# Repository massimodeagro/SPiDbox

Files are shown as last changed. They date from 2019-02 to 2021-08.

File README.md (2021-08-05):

# SPiDbox: a Skinnerbox system to train jumping SPiDers based on the Raspberry Pi

## Before we start
A full description of the SPiDbox, as well as the experimental validation, is available in the Journal of Neuroscience Methods (https://doi.org/10.1016/j.jneumeth.2020.108925). if you use the system, please cite the paper.

## This GitHub page contains:
* In the "3D_models" folder, the .scad files of all the components to 3d print
* In the "OS" folder, the full python script, that will have to be copied in the home folder of the Raspberry Pi (see the installation guide)
* In the "Electronics" folder, a pdf depicting how the circuit needs to be built
* The "screenImages" folder is part of a work in progress. For now, it only needs to be copied inside the home folder of the Raspberry Pi

**Inside each folder you will find a guide for printing, installation and building, respectively.**

For any request or comment, please contact me at *massimo.de-agro@ur.de*. I would like to make the guides as user-friendly as possible, so every suggestion is highly appreciated.

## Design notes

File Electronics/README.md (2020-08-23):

# Preparing the circuit

In this folder, you will find a PDF with the schematic of the circuit. If you wish to make your own circuit board, just follow the schematic. If you instead prefer, you can download the zip containing the Gerber file (this have been generated with easyEDA https://easyeda.com/

## Things you will need

Before starting, you will need to acquire some components. The following are all trough hole components (THC):
* 49 male pin 2.54mm-pitch connectors, like [this](https://www.pololu.com/product/965). Specifically, you will need a 2x20 long strip, a 5 long strip and a 4 long strip.
* 26 female pin 2.54mm-pitch connectors, like [this](https://www.pololu.com/product/1030). Specifically, you will need two 8-long strips and one 10-long strip. If you buy a single long female pin connector strip, be aware that by cutting it you will lose the connector on the cut position, so buy a slightly longer strip.
* A two pin 2.54mm-pitch jst-xh connector, like [this](https://www.pololu.com/product/2717)
* A four-pin 2.54mm-pitch jst-xh connector, of the same type of the one above
* A stepper motor driver. In the schematic, an A4988 is reported, but many drivers have the same pinout structure. Just be sure that the pins positions are the same as in the A4988
* A rotary encoder with its breakout board.
* An SSD1306 OLED screen with its breakout board.
* An ADS1115 analog to digital converted with its breakout board.
* 5 1kohm resistor.
* 1 1N4448 diode.
* 1 BD139 transistor.
* 1 100uf electrolytic capacitor.
* 5 female 3.5mm jack connectors (to solder onto the board, so it needs to be a THC component).
* 5 male 3.5mm jack connectors (to solder to a cable).
* 1 female power jack connector (to solder onto the board, so THC).
* 1 lm2596 buck converter.
* 1 12V, at least 5A power supply.
* 1 female to female 2x20 jumper wire. this is to connect the raspberry to the circuit board.
* 9 female to female jumper wire.
* A 12V led strip.
* A soldering iron and solder.

## Things to do to successfully solder your board

The process of building the board is straight forward, just solder the right components on their places. But you will need to take some care.

* Note that the board has a front and a back side. The front side presents the name of the SPiDbox on the bottom right.
* Solder two 20 long male strips on the raspberry pi slot on the board. The strips need to end up having the long pin sticking out from the back side of the board. So while looking at the board back side, fit in the holes the short end of the pin, then solder the protruding end from the front.
* All other components will stick out from the front face.
* The connectors for the OLED screen and the rotary encoder will be done with the remaining male strip pins, as these two components will not sit on the board, but will be attached to the front of the SPiDbox. 
* For the stepper motor driver and the ADS, use female connectors.
* Next, solder the two jst-xh in their respective places
* Solder in the resistors, the diode and the capacitor (be aware of capacitor polarity)
* Solder in the 3.5mm jacks and the power jack
* Lastly, solder the buck converter

**ATTENTION -- at this point, connect the board to the 12V power supply, BEFORE connecting any components in (drivers, raspberry, ADS, OLED screen, etc.) and regulate the buck converter output voltage to 5V. If you connect the raspberry and the voltage is too high you will burn it**

* Once the voltage is adjusted, you can connect everything up. Be aware of polarity and orientation of every component. For all of them, there is an indication printed on the board. For the raspberry, there is a "+" sign on one side of the connector. That side is the side that has the 5V pins, so orient the connector on the raspberry so that those pins match.
* Use the jumper wires to connect the rotary encoder and the OLED screen
* Lastly, connect the two motors to the 4 pins and 2 pins connector

The 5 3.5mm jacks are of two types. The 4 on the left are for photo-resistor. Connect each lead of the photoresistor with a cable and then to the jack ends. The photoresistor has no polarity, but if you have a 3 ends jack instead of a 2 ends jack, be aware of which 2 of the 3 you use to not create a short. In the current 3d model of the SPiDbox, only 2 photo-resistors are used.
The right jack connector is for the LED strip, needed to illuminate the experimental box. For this, polarity is important, so check with a multimeter which lead gets the +12V

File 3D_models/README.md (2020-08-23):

# 3D printing the SPiDbox

This folder contains all the files needed to fully 3d print the system. the objects have been designed with [OpenSCAD](https://github.com/openscad/openscad).

Currently, I am working on a more aesthetically pleasing version of all the files on [FreeCAD](https://github.com/FreeCAD/FreeCAD), which will be uploaded as soon as it is usable. For now, however, there are still some fitting problems between the parts, the .scad files will do just fine.

## Folders description

### UserInterface

This folder contains only the file `CircuitBox.scad`, which is placed at the bottom of the SPiDbox. The part has a frontal window, in which an oledSSD1306 can be fitted, and a hole, that can contain a rotary encoder. These two components are the core of the user interface. The space inside this part will contain the circuit, other than cables and tubings (see building guide).

### ExperimentalBox

From this folder you will need to print `Exp_box.scad` and `Exp_box_lid.scad`. The other files are imported into the first two for construction. These need to be printed in white, as they will be seen by the spider. You will only need one copy of each.

### CameraAndPiHolder

From this folder, you will need to print one copy of `camhold.scad`. The two STL files are imported into the .scad to construct the camera enclosure. These two STLs have been downloaded from https://www.thingiverse.com/thing:92208. 
Depending on where you buy the camera and depending on its version, it may not fit inside the holder enclosure. If that is the case, you will need to modify slightly that section, either in the file or manually once printed.

### ExchangablePieces

These files represent the exchangeable parts and actuators for the box. You will need at least one `EntranceLid.scad` (that closes the round opening on the front wall of the `Exp_box.scad`), and one `DropDispenser.scad`. `ResistorHolder.scad` is the case for the photo-resistor, you will need to print one for each sensor you want to use. `Cover.scad` is used to plug the unused holes left.

## Printing Suggestions

All pieces should print fine without the need for any support. All the pieces that will get in contact with the spider should be white, meaning the `Exp_box.scad`, the `EntranceLid.scad` and the `DropDispenser.scad` (unless for some experimental reasons you decide otherwise.)

You will need to be aware of your own 3D printer capabilities, especially for the tolerances, as many pieces need to fit together.
The most challenging component will be the `DropDispenser.scad`, as its legs do not represent the most stable base. Adding a brim to the print should be enough to have it print just fine on most printers.
The `DropDispenser.scad` will also have to be printed at a higher temperature to ensure high layer adhesion, and with 100% infill, as the piece must come out watertight

**_Beware:_ depending on the material you will use to print the pieces, you may need to substitute them over time. Especially the `DropDispenser.scad` will inevitably absorb humidity and may become clogged or start dripping if made in PLA. Either choose another material or change the piece every 3 to 4 weeks.**

## Building guide

### List of components

Before you start assembling, be sure to have printed:
* one `CircuitBox.scad` from the *UserInterface* folder
* both `Exp_box.scad` and `Exp_box_lid.scad` files from the *ExperimentalBox* folder
* the `camhold.scad` file from the *CameraAndPiHolder* folder
* at least one `EntranceLid.scad` and one `DropDispenser.scad`, plus two other pieces of your choice between `Cover.scad` and `ResistorHolder.scad` (either one of each or two copies of one of the two) from the folder *ExchangablePieces*

Moreover, you will also need to have:
* the built circuit with all its modules (see the circuit building instructions for more information)
* the OledSSD1306
* a rotary encoder
* a peristaltic pump based on a Nema17 motor
* a second peristaltic pump based on any 5V DC motor
* a Raspberry Pi Zero
* a Raspberry Pi Camera
* flexible tubing with an internal diameter of 2mm (how much you will need depends on your own setup. A couple of meters in total should be enough for most people)
* one photo-resistor for every `ResistorHolder.scad` you printed (but have on the side quite a lot more, they are cheap and can break easily)
* some liquid container, like falcon tubes.
* a square piece of plexiglass

Lastly, you will also need some M2 and M3 nuts and bolts, depending on the circuit board you choose. You will for sure need at least 6 short M2 bolts with their corresponding nuts, to secure the Raspberry and its camera to the printed pieces.

### Assembly

_pictures coming_

1. Screw the Raspberry Pi Zero to the back of `camhold.scad`
  The camera connector on the Raspberry **needs to be oriented towards the top**
2. Insert the camera in its enclosure with the ribbon cable already connected, as it will not be accessible anymore once the camera enclosure is assembled
3. Connect the ribbon cable to the Raspberry Pi
4. Screw the circuit board inside the `CircuitBox.scad`, on the back wall
5. Screw the Oled Screen in the front wall of the `CircuitBox.scad` from the inside
6. Insert the rotary encoder in the hole on the front wall of the `CircuitBox.scad` and screw it in place
7. Place both the DC and the stepper peristaltic pumps near the `CircuitBox.scad`, and insert their cables from the side holes in the circuit box. Connect each one to its designated connector.
8. Fit the output tube of the stepper pump and the input tube of the DC pump inside the `CircuitBox.scad` from the same holes.
9. Connect these two tubes to the two couplers of the `DropDispenser.scad`. You should now have the drop dispenser _inside_ the `CircuitBox.scad`
10. Fit a resistor inside every `ResistorHolder.scad` you printed. Solder to the two legs of the resistor coming out to cables, and connect them to their designated connector on the circuit board. You should now have also the `ResistorHolder.scad` inside the `CircuitBox.scad`
11. Fit the `ResistorHolder.scad` and the `DropDispenser.scad` in their designated holes from the bottom of the `Exp_box.scad`. these pieces can be fit and then rotated 90° to click in place.
12. Lay the `Exp_box.scad` on top of the `CircuitBox.scad`
13. Put a rectangle of plexiglass on top of the `Exp_box.scad`. The plexiglass piece should fit inside the designated groove on top of the `Exp_box.scad`.
14. Place the `Exp_box_lid.scad` on top. It should stop the plexiglass in place.
15. Put the `camhold.scad` on top of the `Exp_box_lid.scad`. Its legs should fit in the 4 holes of the `Exp_box_lid.scad`
16. Connect the raspberry to the circuit board
17. Connect the raspberry to power

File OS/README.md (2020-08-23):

# Install the software

This readme will guide you in the process of installing the software onto your Raspberry Pi. Before starting, be sure to have:
* Your Raspberry Pi zero, that will drive the SPiDbox
  if your Raspberry Pi Zero does not have a wifi receiver (not the W version), you will also need a Raspberry Pi 3B for the installation process
* A USB keyboard
* A USB to micro-USB adapter
* A monitor with HDMI connector
* A HDMI to micro-HDMI adapter or cable
* A wifi internet connection
* A micro-sd card
* A computer that can read micro-sd cards

## Install Raspbian

The first step to install the SPiDbox is to install the Raspberry Pi OS. You will need a micro sd card. The minimum workable size is 8gb, but the bigger it is the longer you can work with it before needing to empty the card from the videos.

1. connect the SD card to your computer and download the raspbian OS https://www.raspberrypi.org/downloads/raspberry-pi-os/. The SPiDbox can work with the "Lite" version of Raspbian. Be aware however that this version has no desktop, so if you don't feel confident with working only with the command line, download the "desktop" version.
2. Connect the SD card, download and install on your computer etcher https://www.balena.io/etcher/. Launch the software and follow instruction to flash the Raspbian os onto the SD card. **This process will wipe any content on your sd-card, so be sure there are no important files inside and that you are selecting the right device**
3. Let the process finish

Note that you can read and write on this sd card only with a Linux computer, or you will need to install dedicated software on your windows or mac computer to make it able to mount and read EXT4 partitions. 

Once able to read the sd, you should be able to see two partitions: one called "boot" and one called "rootfs"

Enter the configuration GUI

## Setup your Raspbian

On this guide, I will describe steps for the "Lite" version of Raspbian, and I will assume you have a keyboard and an HDMI monitor. If you do not have them around and you have experience with raspberry pi, you can set up your Raspbian in "headless" mode by enabling ssh.

1. While the sd-card is still connected to the computer, copy the files from this repository into the raspberry.
      * The files inside the 'OS' folder need to be placed in /home/pi/.
      * Note that 'OS' contains a subfolder, subjs. This folder defines the subjects available for testing. Here is also where the logs and the video will be saved. To insert a new subject, copy the '001' folder and paste it with a new name. The software will recognize the folder names here as the available subjects
      * Also copy the 'screenImages' folder here. Not the content, the whole folder
2. Connect to your Raspberry the keyboard, the screen, insert the sd-card and connect to power
  You do not necessarily need the camera connected for setting up your system, but you can connect it now for testing purposes
3. Once connected to power the raspberry pi will boot. In some minutes it should bring you to the command line
  Note that on your first login, you will be asked to provide the "login", or username, and password. The default username is "pi", the default password is "raspberry"
4. First, let's enable fast login, so you will not be prompted for username and password anymore. Enter the configuration GUI
    ```
    $ sudo raspi-config
    ```
    note, the command sudo will prompt a request for the password.
    choose "Boot Options" -> "Desktop/CLI" and choose "Console autologin".

5. Next, you will need to connect to your wifi. If you closed it from the step before, reopen the configuration GUI
    ```
    $ sudo raspi-config
    ```
    
    select "Localisation Options" -> "Change wireless country" and specify your location. Then close the config
    next, open the `wpa-supplicant` file by the command
    ```
    $ sudo nano /etc/wpa_supplicant/wpa_supplicant.conf
    ```
    go to the bottom of the file and add
    ```
    network={
      ssid="yourwifiname"
      psk="tyourwifiPassword"
    }
    ```
6. now, activate the various interfaces. Go back in the configuration
    ```
    $ sudo raspi-config
    ```
    select "Interfacing Options", from there you need to activate the camera, the SPI and I2C. Then close settings and reboot the system by
     ```
    $ sudo reboot
    ```
7. next, update your system
    ```
    $ sudo apt update
    $ sudo apt upgrade
    ```
8. install dependencies
    
    First, the OLED screen control. The package GitHub page is https://github.com/rm-hull/luma.oled/. We are installing old versions here as the current version only supports python >3.5
    ```
    $ sudo apt install python-dev python-pip libfreetype6-dev libjpeg-dev build-essential libopenjp2-7 libtiff5
    $ sudo -H pip install luma.core==1.6.0
    $ sudo -H pip install luma.oled==2.3.1
    ```
    next, the analog to digital converter control, from Adafruit. This is again an older version for pyton2.7 support
    ```
    $ sudo -H pip install adafruit-ads1x15
    ```
    the python raspberry pi camera module
    ```
    $ sudo -H pip install picamera
    ```
    lastly, fonts support 
    ```
    $ sudo apt install fontconfig
    ```
9. to make so that the software launches on boot, you need to add the code into the  `.bashrc` file. to do so, type
    ```
    $ sudo nano .bashrc
    ```
    scroll to the end of the file and write
    ```
    python mainMenu.py
    ```
    close the file and save.

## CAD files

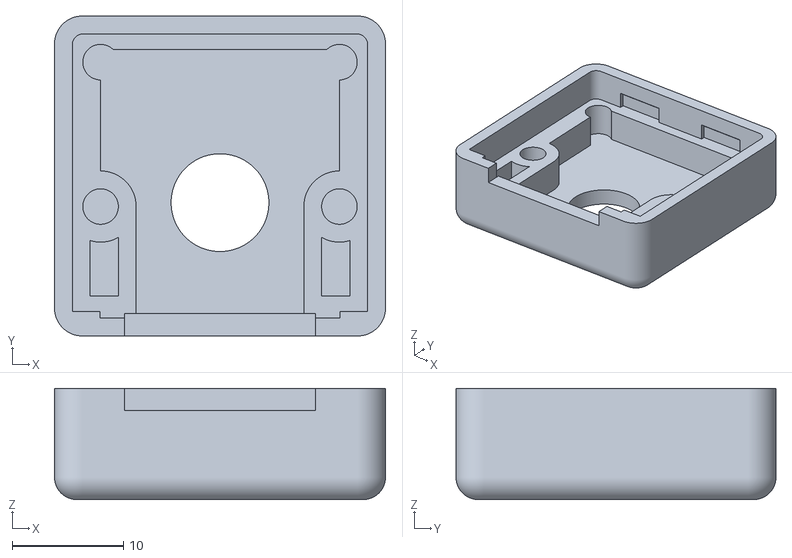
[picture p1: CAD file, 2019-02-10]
3D_models/CameraAndPiHolder/camera_front.STL
29.8 x 28.8 x 10.0

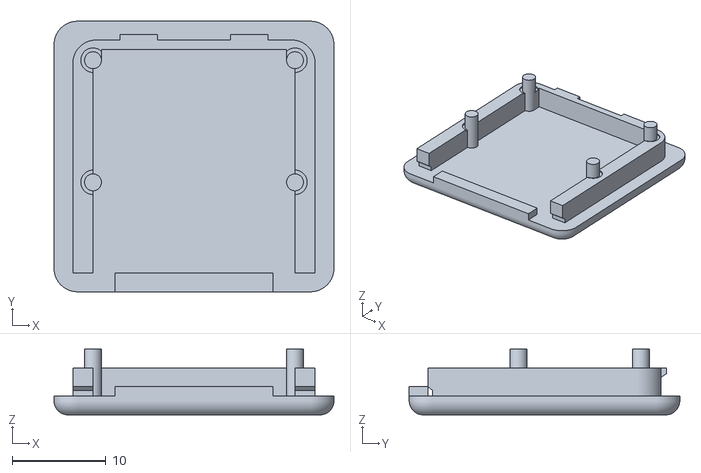
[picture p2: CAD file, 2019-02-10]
3D_models/CameraAndPiHolder/camera_back.STL
29.8 x 28.8 x 7.00

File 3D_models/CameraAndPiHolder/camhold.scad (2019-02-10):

module leg(){
    cube([3,10,140]);
    cube([10,3,140]);
}

module camback(){
    color("blue") translate([-14.9,-12,0]) import("camera_back.STL");
}

module raspholeint(){
    translate([-29,-11.5,0])
    cylinder(h=15,d=3,$fn=30);
    translate([29,-11.5,0])
    cylinder(h=15,d=3,$fn=30);
    translate([-29,11.5,0])
    cylinder(h=15,d=3,$fn=30);
    translate([29,11.5,0])
    cylinder(h=15,d=3,$fn=30);
}
//translate([-14.9,-12,0]) import("camera_front.STL");


camback();
    translate([-45,-45,0]) leg();
    translate([45,-45,0]) rotate([0,0,90]) leg();
    translate([45,45,0])rotate([0,0,180]) leg();
    translate([-45,45,0]) rotate([0,0,-90]) leg();

linear_extrude(height=2) difference(){
square([90,90],center=true);
polygon(points=[[-35,-40],[35,-40],[8,-12],[-8,-12]]);
    rotate([0,0,90]) polygon(points=[[-35,-40],[35,-40],[8,-12],[-8,-12]]);
    rotate([0,0,180]) polygon(points=[[-35,-40],[35,-40],[8,-12],[-8,-12]]);
    rotate([0,0,270]) polygon(points=[[-35,-40],[35,-40],[8,-12],[-8,-12]]);


}

translate([-45,-45,4]) rotate([0,37,0]) cube([5,2,140]);
translate([45,-45,4]) rotate([0,37,90]) cube([5,2,140]);
translate([45,45,4]) rotate([0,37,180]) cube([5,2,140]);
translate([-45,45,4]) rotate([0,37,270]) cube([5,2,140]);

translate([40,-45,4]) rotate([0,-37,0]) cube([5,2,140]);
translate([+45,+40,4]) rotate([0,-37,90]) cube([5,2,140]);
translate([-40,45,4]) rotate([0,-37,180]) cube([5,2,140]);
translate([-45,-40,4]) rotate([0,-37,270]) cube([5,2,140]);

translate([0,-88,-00]) difference(){
    translate([-45,45-2,35]) cube([90,2,70]);

translate ([0,50,70]) rotate([90,90,0]) raspholeint();
}

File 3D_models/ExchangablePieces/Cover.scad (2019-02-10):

include<threads.scad>

translate([0,0,12]) cylinder (d=9.8, h=5,$fn=100);
difference(){
    cylinder(d=9.8,h=12,$fn=30);
    translate([12,0,5]) sphere(d=20);
    translate([12,0,0]) cylinder(d=20,h=5, $fn=40);
    translate([-12,0,5]) sphere(d=20);
    translate([-12,0,0]) cylinder(d=20,h=5, $fn=40);
}

translate([0,9.7/2,14.2]) sphere(d=2,$fn=100); 
translate([0,-9.7/2,14.2]) sphere(d=2,$fn=100);

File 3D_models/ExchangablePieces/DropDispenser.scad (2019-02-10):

include <threads.scad>

 module adapter(){
 difference(){
    union(){
        //translate([0,0,8]) cylinder(d2=6,d1=4,h=1.5, $fn=30);
        translate([0,0,9.5]){
            cylinder(d=4,h=5.5, $fn=30);
            cylinder(d2=4,d1=5.5,h=3, $fn=30);
        }
        cylinder(d=4.3,h=10, $fn=30);

    }
    translate([0,0,-30]) cylinder(d=1.5,h=50, $fn=30);
}
}

module key(){
    difference(){
    cylinder(d1=13, d2=9.8,h=12,$fn=30);
    translate([13,0,2]) sphere(d=20);
    translate([13,0,0]) cylinder(d=20,h=2, $fn=40);
    translate([-13,0,2]) sphere(d=20);
    translate([-13,0,0]) cylinder(d=20,h=2, $fn=40);
}
}

difference(){
    union(){
        difference(){
                union(){
                    translate([0,0,12]) cylinder (d=9.8, h=5,$fn=100);
                    key();

                }
                
            translate([0,0,2]) cylinder(d2=1.5,d1=1.5,h=9,$fn=20); 
            translate([0,0,11]) cylinder(d1=1.5,d2=3,h=6,$fn=50);
            //rotate([0,-2,0]) translate([3.9,0,-5]) cylinder(d=1.5,h=30,$fn=20);
            translate ([0,4.5,2.3]) rotate([90,0,0]) cylinder(d=3,h=9,$fn=30);
            translate ([0,4,-1]) cylinder(d=1.5,h=3,$fn=30);
            translate ([0,-4,-1]) cylinder(d=1.5,h=3,$fn=30);
        }

        translate([0,4,0]) rotate([180,0,0]) adapter();
        translate([0,-4,0]) rotate([180,0,0]) adapter();
        difference(){
            union(){
            translate([0,-4,-5]) rotate([-11.6,0,0]) cylinder(d1=4,d2=8,h=6,$fn=30);
            translate([0,4,-5]) rotate([11.6,0,0]) cylinder(d1=4,d2=8,h=6,$fn=30);
            }
                      
        difference(){
        cylinder(d=20, h=20);
            key();
        }
    }
    }
     translate ([0,4,-20]) cylinder(d=1.5,h=22,$fn=30);
     translate ([0,-4,-20]) cylinder(d=1.5,h=22,$fn=30);
    translate([0,0,20]) cylinder(d=70,h=20);
    

//translate([0,0,7]) cylinder(d=200,h=20);
}

translate([0,9.7/2,14.2]) sphere(d=2,$fn=100); 
translate([0,-9.7/2,14.2]) sphere(d=2,$fn=100);

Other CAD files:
3D_models/ExchangablePieces/EntraceLid.scad
3D_models/ExchangablePieces/ResistorHolder.scad
3D_models/ExperimentalBox/Exp_box.scad
3D_models/ExperimentalBox/Exp_box_lid.scad
3D_models/ExperimentalBox/clip.scad
3D_models/ExperimentalBox/e-paper2.9.scad
3D_models/UserInterface/structure.scad

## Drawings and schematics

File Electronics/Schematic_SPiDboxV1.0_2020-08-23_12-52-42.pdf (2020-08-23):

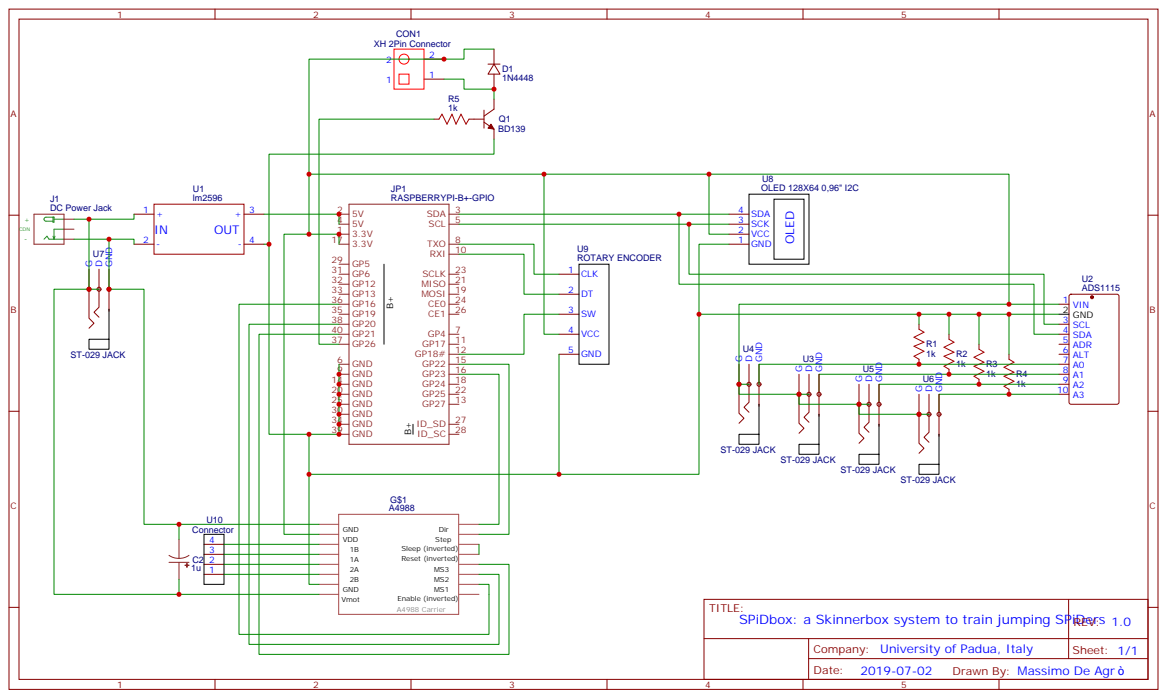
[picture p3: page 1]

TITLE:
SPiDbox: a Skinnerbox system to train jumping SPiDers REV: 1.0

Company: University of Padua, Italy

Drawn By: Massimo De Agr

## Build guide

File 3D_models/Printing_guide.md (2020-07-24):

# 3D printing the SPiDbox

This folder contains all the .scad files needed to fully 3d print the system. They are divided in thematic subfolders.

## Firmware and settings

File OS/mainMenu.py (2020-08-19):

"""
SPiDbox software

This file should be called by the Raspberry Pi automatically at startup. 
It contains the SPiDbox menu and is responsible for calling every other files

@author: Massimo De Agro'
"""
#importing general modules
import logging # for logging info and errors

import datetime #to be unified
import time #to be unified

import os #load folders


#modules for user screen control
from luma.core.interface.serial import i2c
from luma.core.render import canvas
from luma.oled.device import ssd1306
from PIL import ImageFont #load fonts

#modules to input and output
import RPi.GPIO as GPIO
import Adafruit_ADS1x15 #read I2C analog to digital converter

#custom modules
import pin #contains definitions for every pin
import icons #contains pictures used in the menu
from lists import subjs, loadsubjs #formulas to load and create subjects
import photo #contains formula for reading photosensors
from rotary import rothread #reads the rotary encored

#training procedures
from habitScreen import habit #habituation phase. No sensors, only dispenser
from trainNoScreen import trainNS #testing phase without the screen. differently coloured sensors

#define I2C modules
serial = i2c(port=1, address=0x3C) #user screen
device = ssd1306(serial) #define user screen model
W, H = (128,64) #define user screen size

adc = Adafruit_ADS1x15.ADS1115(address=0x48) #photoresistor I2C


def pixelart (drawobj,pic,offset,neg): #to draw pictures on the user screen
    if neg ==1: #negative
        col1="black"
        col2="white"
    else:
        col1="white"
        col2="black"
    for y, row in enumerate(pic):
        for x, cell in enumerate(row):
            if cell == 1:
                drawobj.point((x+1+offset[0],y+1+offset[1]), fill=col1)
            if cell == 0:
                drawobj.point((x+1+offset[0],y+1+offset[1]), fill=col2)
  
#load fonts
font = ImageFont.truetype("/usr/share/fonts/truetype/dejavu/DejaVuSans-Bold.ttf",16)
fontT = ImageFont.truetype("/usr/share/fonts/truetype/dejavu/DejaVuSans-Bold.ttf",15)



###%%% MAIN MENU %%%###

#menu entry names
tabs = ['launch','settings'] #main entry
tests = ['back','habituation','trainLR'] #"launch" submenu
setups = ['back','prime','clean', 'resistors','subjs','turn off'] #"settings" submenu

#creating state variable used to navigate the menu
select = 0
case = 0    #keeps track of the current menu position. it changes by rotating the knob
casechange=0

with canvas(device) as draw: #draw startup logo
    pixelart(draw,icons.logo,(0,0),0)
time.sleep(2) #show for 2 seconds

while True: #enters in an infinite loop displaying the menu
    with canvas(device) as draw: #this writes line by line all the voices from the "tabs" list
        for n, line in enumerate(tabs):
             #text is drawn according to the current case: the selected one is on the centre, the other are moved on top or bottom 
            draw.text((17,24+(n*20)-(case*20)), line, font=font, fill="white") 
            pixelart(draw,icons.arrow,(0,26),0) #draw an arrow at the centre point
    tout = rothread(pin.cl,pin.dt,pin.sw) #read the knob. this will not output until something happens (rotated or clicked)
    #for a more complete explanation see rotary.py
    if tout!=0: #it it was rotated
        case+=tout #change the case
        logging.info('Rotated the knob')
        if case<0: #if the case is now a negative number however
            case=0 #put it back at 0
        elif case>len(tabs)-1: #also, if the case number is higher than the total cases we have
            case=len(tabs)-1 #put it at that number. In this case here it will be 1
    else: #if it was clicked
        logging.info('Clicked')
        time.sleep(0.3) #debounce
        
        #here we get in the case was currently selected when we clicked. it is a deep if/elif section, catching all the possible cases
        #and acting accordingly
        #%% launchables
        if case==0: #if we clicked case 0, we get into the "launch menu
            logging.info('Got in launch menu')
            case=0 #reset case number
            while True: #infinite loop to display the new menu
                #this works exactly like the main menu.
                with canvas(device) as draw:
                    for n, line in enumerate(tests):
                        draw.text((17,24+(n*20)-(case*20)), line, font=font, fill="white")
                        pixelart(draw,icons.arrow,(0,26),0)
                tout = rothread(pin.cl,pin.dt,pin.sw)
                if tout!=0:
                    logging.info('Rotated the knob')
                    case+=tout
                    if case<0:
                        case=0
                    elif case>len(tests)-1:
                        case=len(tests)-1
                else:
                    logging.info('Clicked')
                    time.sleep(0.3)
                    #if/elif section for the various cases
                    if case == 0: #now case 0 is "back". it breaks out of the current while loop and goes up to the previous menu
                        logging.info('Back to start menu')
                        case = 0
                        break
                    elif case ==1: #case 1 launch the habituation routine
                        logging.info('Got in screen habit mode')
                        case=0 #reset case
                        while True:
                            with canvas(device) as draw: #this shows all the avalable subjects
                                for n, line in enumerate(subjs):
                                    draw.rectangle(((0,0),(128,20)),"white")
                                    draw.text((6,0), 'subject', font=fontT, fill="black")
                                    draw.text((17,24+(n*20)-(case*20)), line, font=font, fill="white")
                                    pixelart(draw,icons.arrow,(0,26),0)
                            #Now we can choose the subject
                            tout = rothread(pin.cl,pin.dt,pin.sw)
                            if tout!=0:
                                logging.info('Rotated the knob')
                                case+=tout
                                if case<0:
                                    case=0
                                elif case>len(subjs)-1:
                                    case=len(subjs)-1
                            else:
                                logging.info('Clicked')
                                time.sleep(0.3)
                                name = subjs[case]
                                break
                        if name!='back': #if we did not click on back
                            testnum = 1 #initialize test number
                            while True:
                                with canvas(device) as draw: #show number
                                    draw.rectangle(((0,0),(128,20)),"white")
                                    draw.text((6,0), 'habitS num', font=fontT, fill="Black")
                                    draw.text((60,26), str(testnum), font=font, fill="white")
                                tout = rothread(pin.cl,pin.dt,pin.sw) #rotating increase or decrease number
                                if tout!=0:
                                    logging.info('Rotated the knob')
                                    testnum+=tout
                                else: #clicking choses the number
                                    logging.info('Clicked')
                                    time.sleep(0.3)
                                    test = str(testnum)
                                    break
                            with canvas(device) as draw: #show the decisions made until now: training routine chosen, subject and number
                                draw.rectangle(((0,0),(128,64)),"white")
                                draw.text((0,20), name+'_habitS_'+str(testnum), font=font, fill="black")
                            time.sleep(2) #show for 2 seconds
                                        
                            logging.info('Starting Screen Habit')
                            start=datetime.datetime.now() #set starting time
                            habit(name,test,start,canvas, device,font, fontT) #start the experiment. see related file                     
                    
                    #same code is more or less repeated for the other training routines, with few variations related to the
                    #experiment's needs (like decide if left or right is the correct for the current subject
                    elif case ==2:
                        logging.info('Got in left and right mode')
                        case=0
                        while True:
                            with canvas(device) as draw:
                                for n, line in enumerate(['left','right']):
                                    draw.rectangle(((0,0),(128,20)),"white")
                                    draw.text((6,0), 'correct side', font=fontT, fill="black")
                                    draw.text((17,24+(n*20)-(case*20)), line, font=font, fill="white")
                                    pixelart(draw,icons.arrow,(0,26),0)
                            tout = rothread(pin.cl,pin.dt,pin.sw)
                            if tout!=0:
                                logging.info('Rotated the knob')
                                case+=tout
                                if case<0:
                                    case=0
                                elif case>len(['left','right'])-1:
                                    case=len(['left','right'])-1
                            else:
                                logging.info('Clicked')
                                time.sleep(0.3)
                                side = ['left','right'][case]
                                break
                        while True:
                            with canvas(device) as draw:
                                for n, line in enumerate(subjs):
                                    draw.rectangle(((0,0),(128,20)),"white")
                                    draw.text((6,0), 'subject', font=fontT, fill="black")
                                    draw.text((17,24+(n*20)-(case*20)), line, font=font, fill="white")
                                    pixelart(draw,icons.arrow,(0,26),0)
                            tout = rothread(pin.cl,pin.dt,pin.sw)
                            if tout!=0:
                                logging.info('Rotated the knob')
                                case+=tout
                                if case<0:
                                    case=0
                                elif case>len(subjs)-1:
                                    case=len(subjs)-1
                            else:
                                logging.info('Clicked')
                                time.sleep(0.3)
                                name = subjs[case]
                                break
                        if name!='back':
                            testnum = 1
                            while True:
                                with canvas(device) as draw:
                                    draw.rectangle(((0,0),(128,20)),"white")
                                    draw.text((6,0), 'trainLR num', font=fontT, fill="Black")
                                    draw.text((60,26), str(testnum), font=font, fill="white")
                                tout = rothread(pin.cl,pin.dt,pin.sw)
                                if tout!=0:
                                    logging.info('Rotated the knob')
                                    testnum+=tout
                                else:
                                    logging.info('Clicked')
                                    time.sleep(0.3)
                                    test = str(testnum)
                                    break
                            with canvas(device) as draw:
                                draw.rectangle(((0,0),(128,64)),"white")
                                draw.text((0,20), name+'_trainLR_'+str(testnum), font=font, fill="black")
                            time.sleep(2)
                            
                            logging.info('Started train screen')
                            start=datetime.datetime.now()
                            trainNS(name,test,side,start,canvas, device,font, fontT)  
                            
        #%% settings section. the overall structure is similar to the launchables                      
        elif case==1:
            case=0
            while True:
                with canvas(device) as draw:
                    for n, line in enumerate(setups):
                        draw.text((17,24+(n*20)-(case*20)), line, font=font, fill="white")
                        pixelart(draw,icons.arrow,(0,26),0)
                tout = rothread(pin.cl,pin.dt,pin.sw)
                if tout!=0:
                    case+=tout
                    if case<0:
                        case=0
                    elif case>len(setups)-1:
                        case=len(setups)-1
                else:
                    time.sleep(0.3) 
                    
                    #if we choose back, break from this loop
                    if case == 0:
                        break
                    #pump priming. The pump rotates continously until prompted to stop
                    elif case ==1:
                        with canvas(device) as draw:
                            draw.rectangle(((0,0),(128,20)),fill='white')
                            draw.text((0,0), 'priming pump', font=fontT, fill="black")
                            draw.text((0,25), 'press ok to stop', font=font, fill="white") 
                        while True:
                            GPIO.output(pin.dc, GPIO.HIGH) #turn on DC pump to suck liquid away
                            
                            #do one stepper pump step
                            GPIO.output(pin.stp,GPIO.HIGH) 
                            time.sleep(0.001)
                            GPIO.output(pin.stp,GPIO.LOW)
                            time.sleep(0.001)
                            
                            #if rotary encoder is clicked
                            if not GPIO.input(pin.sw):
                                time.sleep(0.3)
                                GPIO.output(pin.dc, GPIO.LOW) #turn off sucking pump
                                break #and exit from this while
        
                        with canvas(device) as draw:
                            draw.rectangle(((0,0),(128,20)),fill='white')
                            draw.text((0,0), 'fine tune pump', font=fontT, fill="black")
                            draw.text((0,25), 'press ok to stop', font=font, fill="white") 
                        
                        while True: #now, rotating the encoder rotates the pump. we want to fine tune the pump until it is in the right position
                            tout = rothread(pin.cl,pin.dt,pin.sw)
                            if tout!=0:
                                if tout>0:
                                    GPIO.output(pin.stp,GPIO.HIGH)
                                    time.sleep(0.001)
                                    GPIO.output(pin.stp,GPIO.LOW)
                                    time.sleep(0.001)
                                elif tout<0:
                                    GPIO.output(pin.clk,GPIO.HIGH)
                                    GPIO.output(pin.stp,GPIO.HIGH)
                                    time.sleep(0.001)
                                    GPIO.output(pin.stp,GPIO.LOW)
                                    time.sleep(0.001)
                                    GPIO.output(pin.clk,GPIO.LOW)
                            else:
                                time.sleep(0.3)
                                break  
                        GPIO.output(pin.dc, GPIO.HIGH)
                        time.sleep(0.8)
                        GPIO.output(pin.dc, GPIO.LOW)
                    
                    #cleaning the pump works exacly as priming, but it lacks the fine tuning
                    elif case ==2:
                        with canvas(device) as draw:
                            draw.rectangle(((0,0),(128,20)),fill='white')
                            draw.text((0,0), 'cleaning pump', font=fontT, fill="black")
                            draw.text((0,25), 'press ok to stop', font=font, fill="white") 
                        while True:
                            GPIO.output(pin.dc, GPIO.HIGH)
                            GPIO.output(pin.stp,GPIO.HIGH)
                            time.sleep(0.001)
                            GPIO.output(pin.stp,GPIO.LOW)
                            time.sleep(0.001)
                            if not GPIO.input(pin.sw):
                                time.sleep(0.3)
                                GPIO.output(pin.dc, GPIO.LOW)
                                break      
                    
                    # to test photosensor. for an explanation of the system see photo.py
                    elif case == 3:
                        adc_filtL = adc.read_adc(pin.photoL, gain=1)
                        adc_EavgL = adc_filtL*1.0
                        adc_filtR = adc.read_adc(pin.photoR, gain=1)
                        adc_EavgR = adc_filtR*1.0
                        while True:
                            L, adc_filtL = photo.binphoto (adc, pin.photoL, photo.filt_c,photo.tresh_c,adc_filtL,adc_EavgL)
                            R, adc_filtR = photo.binphoto (adc, pin.photoR, photo.filt_c,photo.tresh_c,adc_filtR,adc_EavgR)
                            if L == 0:
                                adc_EavgL = photo.Eavgcalc(adc_filtL, adc_EavgL,photo.Eavg_c)
                                print("gothere")
                            if R == 0:
                                adc_EavgR = photo.Eavgcalc(adc_filtR, adc_EavgR,photo.Eavg_c)
                            
                            print (str(adc_filtL)+" - "+str(adc_EavgL)+" - "+str(L) )

                            with canvas(device) as draw:
                                draw.rectangle(((0,0),(128,20)),fill='white')
                                draw.text((0,0), 'Testing Resistors', font=fontT, fill="black")
                                draw.text((20,25), 'L', font=font, fill="white") 
                                draw.text((108,25), 'R', font=font, fill="white") 
                                draw.text((20,50), str(L), font=font, fill="white") 
                                draw.text((108,50), str(R), font=font, fill="white") 
                            if not GPIO.input(pin.sw):
                                time.sleep(0.3)
                                break 
                    #define new subjects
                    elif case == 4:
                        letters = ['a','b','c','d','e','f','g','h','i',
                                   'j','k','l','m','n','o','p','q','r',
                                   's','t','u','v','w','x','y','z','_'] #avalable charcters
                        currletter = 0 #like case
                        spot = 0 #in what character of the name are we
                        name='a' #starting name
                        while True:
                            name = list(name)
                            name[spot] = letters[currletter] #change the character of the name selecting among letters
                            name = ''.join(name) #put the name together
                            with canvas(device) as draw: #show
                                w, h = draw.textsize('new subj')
                                draw.text((25,0), 'new subj', font=fontT, fill="white")
                                w, h = draw.textsize(name)
                                draw.text(((W-w)/2,(H-h)/2), name, font=font, fill="white")
                            tout = rothread(pin.cl,pin.dt,pin.sw)
                            if tout[0]!=0: #if rotated, change currletter
                                currletter+=tout[0]
                                if currletter<0:
                                    currletter=len(letters)-1
                                elif currletter>len(letters)-1:
                                    currletter=0
                                name = list(name)
                                name[spot] = letters[currletter]
                                name = ''.join(name)
                            else: #if clicked
                                if letters[currletter] == '_': #if i selected _, end the name
                                    if name!='_': #if the name is not just a _, create the folder and exit
                                        name = name[0:-1]
                                        os.makedirs('subjs/'+name)
                                        os.makedirs('subjs/'+name+'/video')
                                        os.makedirs('subjs/'+name+'/logs')
                                        subjs = loadsubjs()
                                    time.sleep(0.3)
                                    
                                    break
                                else: #for any other letter
                                    spot += 1 #freeze the character and go ti the next
                                    if spot+1>len(name):
                                        name = name+'a' #and add a letter
                                        time.sleep(0.3)
                    #turn off
                    elif case == 5:
                        os.system('sudo shutdown')

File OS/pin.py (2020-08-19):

"""
SPiDbox 

this file contains the definition for all the pins of the system

@author: Massimo De Agro'
"""

import RPi.GPIO as GPIO #module that control the pins

dc = 37 #DC peristaltic pump pin
 
#Stepper peristaltic pump
stp = 15 #pin that drives motor steps
clk = 16 #pin for direction

# values to make the stepper motor do microsteps. These are generally turned off
M1 = 40
M2 = 38
M3 = 36

# rotary encoder
cl = 8 #clock pin of the rotary
dt = 10 #dt pin of the rotary
sw = 12 #switch. defined also as ok for clarity in some formulas
ok = 12

led = 35 # not used anymore

#photoresistors channels on i2c
photoL = 0
photoR = 1

GPIO.setmode(GPIO.BOARD) #set board mode

#set rotor pins as input
GPIO.setup(cl,GPIO.IN,pull_up_down=GPIO.PUD_UP)
GPIO.setup(dt,GPIO.IN,pull_up_down=GPIO.PUD_UP)
GPIO.setup(sw,GPIO.IN,pull_up_down=GPIO.PUD_UP)

GPIO.setup(led,GPIO.OUT) #not used anymore

# set dc motor as output and then put it low
GPIO.setup(dc,GPIO.OUT)
GPIO.output(dc,GPIO.LOW)

#set peristaltic as out and then put it low
GPIO.setup(stp,GPIO.OUT)
GPIO.output(stp,GPIO.LOW)

GPIO.setup(clk,GPIO.OUT)
GPIO.output(clk,GPIO.LOW)

#old photoresistor method. I keep it for transparency
#GPIO.setup(photoL, GPIO.IN, pull_up_down=GPIO.PUD_UP)
#GPIO.setup(photoR, GPIO.IN, pull_up_down=GPIO.PUD_UP)

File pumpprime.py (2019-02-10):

# -*- coding: utf-8 -*-
"""
Created on Wed Nov 22 19:50:43 2017

@author: frogmax
"""
import RPi.GPIO as GPIO
import time

import pin
def pumpprime(canvas, device, font, fontT, dc,stp,clk):
    GPIO.output(dc, GPIO.HIGH)
    with canvas(device) as draw:
        draw.text((20,0), 'priming pump', font=fontT, fill="white")
        draw.text((23,24), 'press O to stop', font=font, fill="white")
            
    while True:
        GPIO.output(stp,GPIO.HIGH)
        time.sleep(0.0025)
        GPIO.output(stp,GPIO.LOW)
        time.sleep(0.0025)
        if not GPIO.input(pin.ok):
            break
    GPIO.output(dc, GPIO.LOW)
def finetune(canvas, device, font, fontT, dc, stp, clk):
    with canvas(device) as draw:
        draw.text((20,0), 'fine tuneing', font=fontT, fill="white")
        draw.text((15,16), '^ = 1 step fwd', font=font, fill="white")
        draw.text((15,33), 'v = 1 step bkw', font=font, fill="white")
        draw.text((22,50), 'O to quit', font=font, fill="white")
    while True:
        if not GPIO.input(pin.down):
            GPIO.output(clk,GPIO.HIGH)
            GPIO.output(stp,GPIO.HIGH)
            time.sleep(0.05)
            GPIO.output(stp,GPIO.LOW)
            time.sleep(0.05)
            GPIO.output(clk,GPIO.LOW)
        if not GPIO.input(pin.up):
            GPIO.output(stp,GPIO.HIGH)
            time.sleep(0.05)
            GPIO.output(stp,GPIO.LOW)
            time.sleep(0.05)
        if not GPIO.input(pin.ok):
            break
    

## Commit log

2019-02-10 Uploading 3D printable files of the box
    [Cover.scad, DropDispenser.scad, EntraceLid.scad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]
2019-02-10 Uploading circuits
2019-10-14 Delete pumpprime.py
    was part of an old version
2020-07-24 Update and rename Printing_guide.md to README.md
2020-08-23 Uploaded new circuit
2020-10-08 Update drop.py
    Simplified, to just work for 1/6 of turns, to avoid overlapping of similar systems that count the exact number of steps
    [drop.py]
2020-10-08 Update habitScreen.py
    corrected mistake: moved pos variable definition outside the while loop
    [habitScreen.py]
